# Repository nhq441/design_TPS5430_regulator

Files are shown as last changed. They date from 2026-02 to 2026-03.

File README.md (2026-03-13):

# TPS5430 Dual Buck Converter Module










---

## 📖 Introduction

This project presents the design and implementation of a **DC/DC Buck Converter (Step-Down) Power Supply Module** using **two Texas Instruments TPS5430** ICs. The module accepts a wide input voltage range of **14.4V – 25.2V** and delivers multiple regulated output rails suitable for embedded systems and microcontroller-based applications.

Key features include a **3-mode adjustable main output (VP)**, dual auxiliary LDO rails, a **Power Good LED indicator**, and a **configurable overcurrent protection** threshold set via a shunt resistor.

**Course:** Power Electronics and Applications — Course Code: `BTL_DTCSUD`

---

## 🖼️ PCB Images

### Schematic Overview
> 📷 *[Insert full schematic image here]*

---

### PCB Layout — Top Layer


---

### PCB Layout — Bottom Layer


---

### 3D Render




---

### Assembled Board
> 📷 *[Insert photo of the soldered/assembled board here]*

---

## ⚙️ Technical Specifications

| Parameter | Value | Notes |
| :--- | :--- | :--- |
| **Input Voltage ($V_{IN}$)** | 14.4V – 25.2V | Recommended operating range |
| **Main Output VP** | **5V / 12V / 3.3–12V** | 3 selectable modes |
| **VP Output Current** | Max **3A** | High-efficiency switching mode |
| **Auxiliary Output 1** | **5V** | Via LDO, for logic circuits |
| **Auxiliary Output 2** | **3.3V** | Via LDO, for MCUs (ESP32, STM32, etc.) |
| **Switching Frequency** | 500 kHz | Fixed internal oscillator |
| **Buck IC** | 2× TPS5430 | Texas Instruments |
| **Overcurrent Protection** | Configurable | Set via shunt resistor value |
| **Power Good Indicator** | LED (VP rail) | Signals stable output on VP |

---

## 🛠️ Design Details

### 1. Dual TPS5430 Architecture

The module employs **two independent TPS5430 ICs**:
- **IC1:** Drives the main output rail **VP**, supporting 3 selectable voltage modes.
- **IC2:** *(Describe the role of the second IC here — e.g., secondary rail, redundancy, or higher current capacity)*

### 2. Three-Mode Main Output (VP)

The VP rail supports three operating modes, selected via a switch or jumper:

| Mode | Output Voltage | Configuration |
| :---: | :---: | :--- |
| **Mode 1** | **5V** | Fixed feedback resistor network |
| **Mode 2** | **12V** | Fixed feedback resistor network |
| **Mode 3** | **3.3V – 12V** | Adjustable via potentiometer |

### 3. Feedback Network Calculation

The output voltage is set by a resistor divider ($R_1$, $R_2$) connected to the **VSENSE** pin, based on the internal reference $V_{ref} = 1.221V$:

$$V_{OUT} = V_{ref} \times \left(1 + \frac{R_1}{R_2}\right)$$

**With $R_1 = 10k\Omega$ (fixed):**

- **5V Mode:**

$$R_2 = \frac{R_1 \times V_{ref}}{V_{OUT} - V_{ref}} = \frac{10000 \times 1.221}{5.0 - 1.221} \approx 3.24k\Omega$$

- **12V Mode:**

$$R_2 = \frac{10000 \times 1.221}{12.0 - 1.221} \approx 1.13k\Omega$$

- **Variable Mode:** $R_2$ is replaced with a **5kΩ potentiometer in series with a 1kΩ fixed resistor**, allowing continuous adjustment from **3.3V to 12V**.

### 4. Auxiliary LDO Outputs (5V & 3.3V)

Both LDO regulators are cascaded from the **5V Buck output**, not directly from $V_{IN}$:
- **Reason:** Reduces the voltage drop across each LDO, minimizing power dissipation ($P_D = \Delta V \times I_{load}$).
- **Benefit:** Allows the use of compact packages (e.g., SOT-223) without thermal issues.

### 5. Power Good LED Indicator

A **Power Good LED** is connected to the VP rail. The LED lights up when VP reaches its target voltage, confirming stable regulation before connecting a load.

### 6. Configurable Overcurrent Protection

A **low-side shunt resistor** sets the overcurrent trip threshold. Changing the resistor value adjusts the protection level to match the target application's requirements. The sensing node is labeled **ISENSE** in the schematic.

---

## 📂 Project Structure

```text
BTL_DTCSUD/
├── docs/                       # Documentation & Report files
│   └── ...
├── Kicad/                      # Hardware Design Files
│   └── Buck_TPS5430/
│       ├── *.kicad_sch         # Schematic file
│       ├── *.kicad_pcb         # PCB Layout file
│       └── ...
├── reference/                  # Datasheets & Assignment requirements
│   └── ...
├── .gitignore
├── GIT_GUIDE
└── README.md
```

---

## 🚀 Getting Started

### Prerequisites
- **[KiCad EDA](https://www.kicad.org/)** — Version 9.0 or higher recommended
- **[Git](https://git-scm.com/)** — For version control

### Installation

**Option 1: Clone via Git (Recommended)**
```bash
git clone https://github.com/nhq441/design_TPS5430_regulator.git
```

**Option 2: Download ZIP**
1. Click the green **<> Code** button at the top right of this repository page.
2. Select **Download ZIP**.
3. Extract the `.zip` file to your working directory.

### Opening the Project
1. Launch **KiCad**.
2. Navigate to: `Kicad/Buck_TPS5430/`
3. Open: `Buck_TPS5430.kicad_pro`

---

## 🤝 Contributing

This project follows the **Gitflow Workflow**:

- **`main`**: Stable, verified designs only.
- **`develop`**: Primary integration branch for ongoing work.
- **`feature/*`**: Individual feature branches (e.g., `feature/Schematic`, `feature/PCB-Layout`).
  - Always branch from `develop` and merge back via Pull Request.

---

## 📄 License

This project is developed for **educational purposes** within the scope of the **Power Electronics and Applications** course.

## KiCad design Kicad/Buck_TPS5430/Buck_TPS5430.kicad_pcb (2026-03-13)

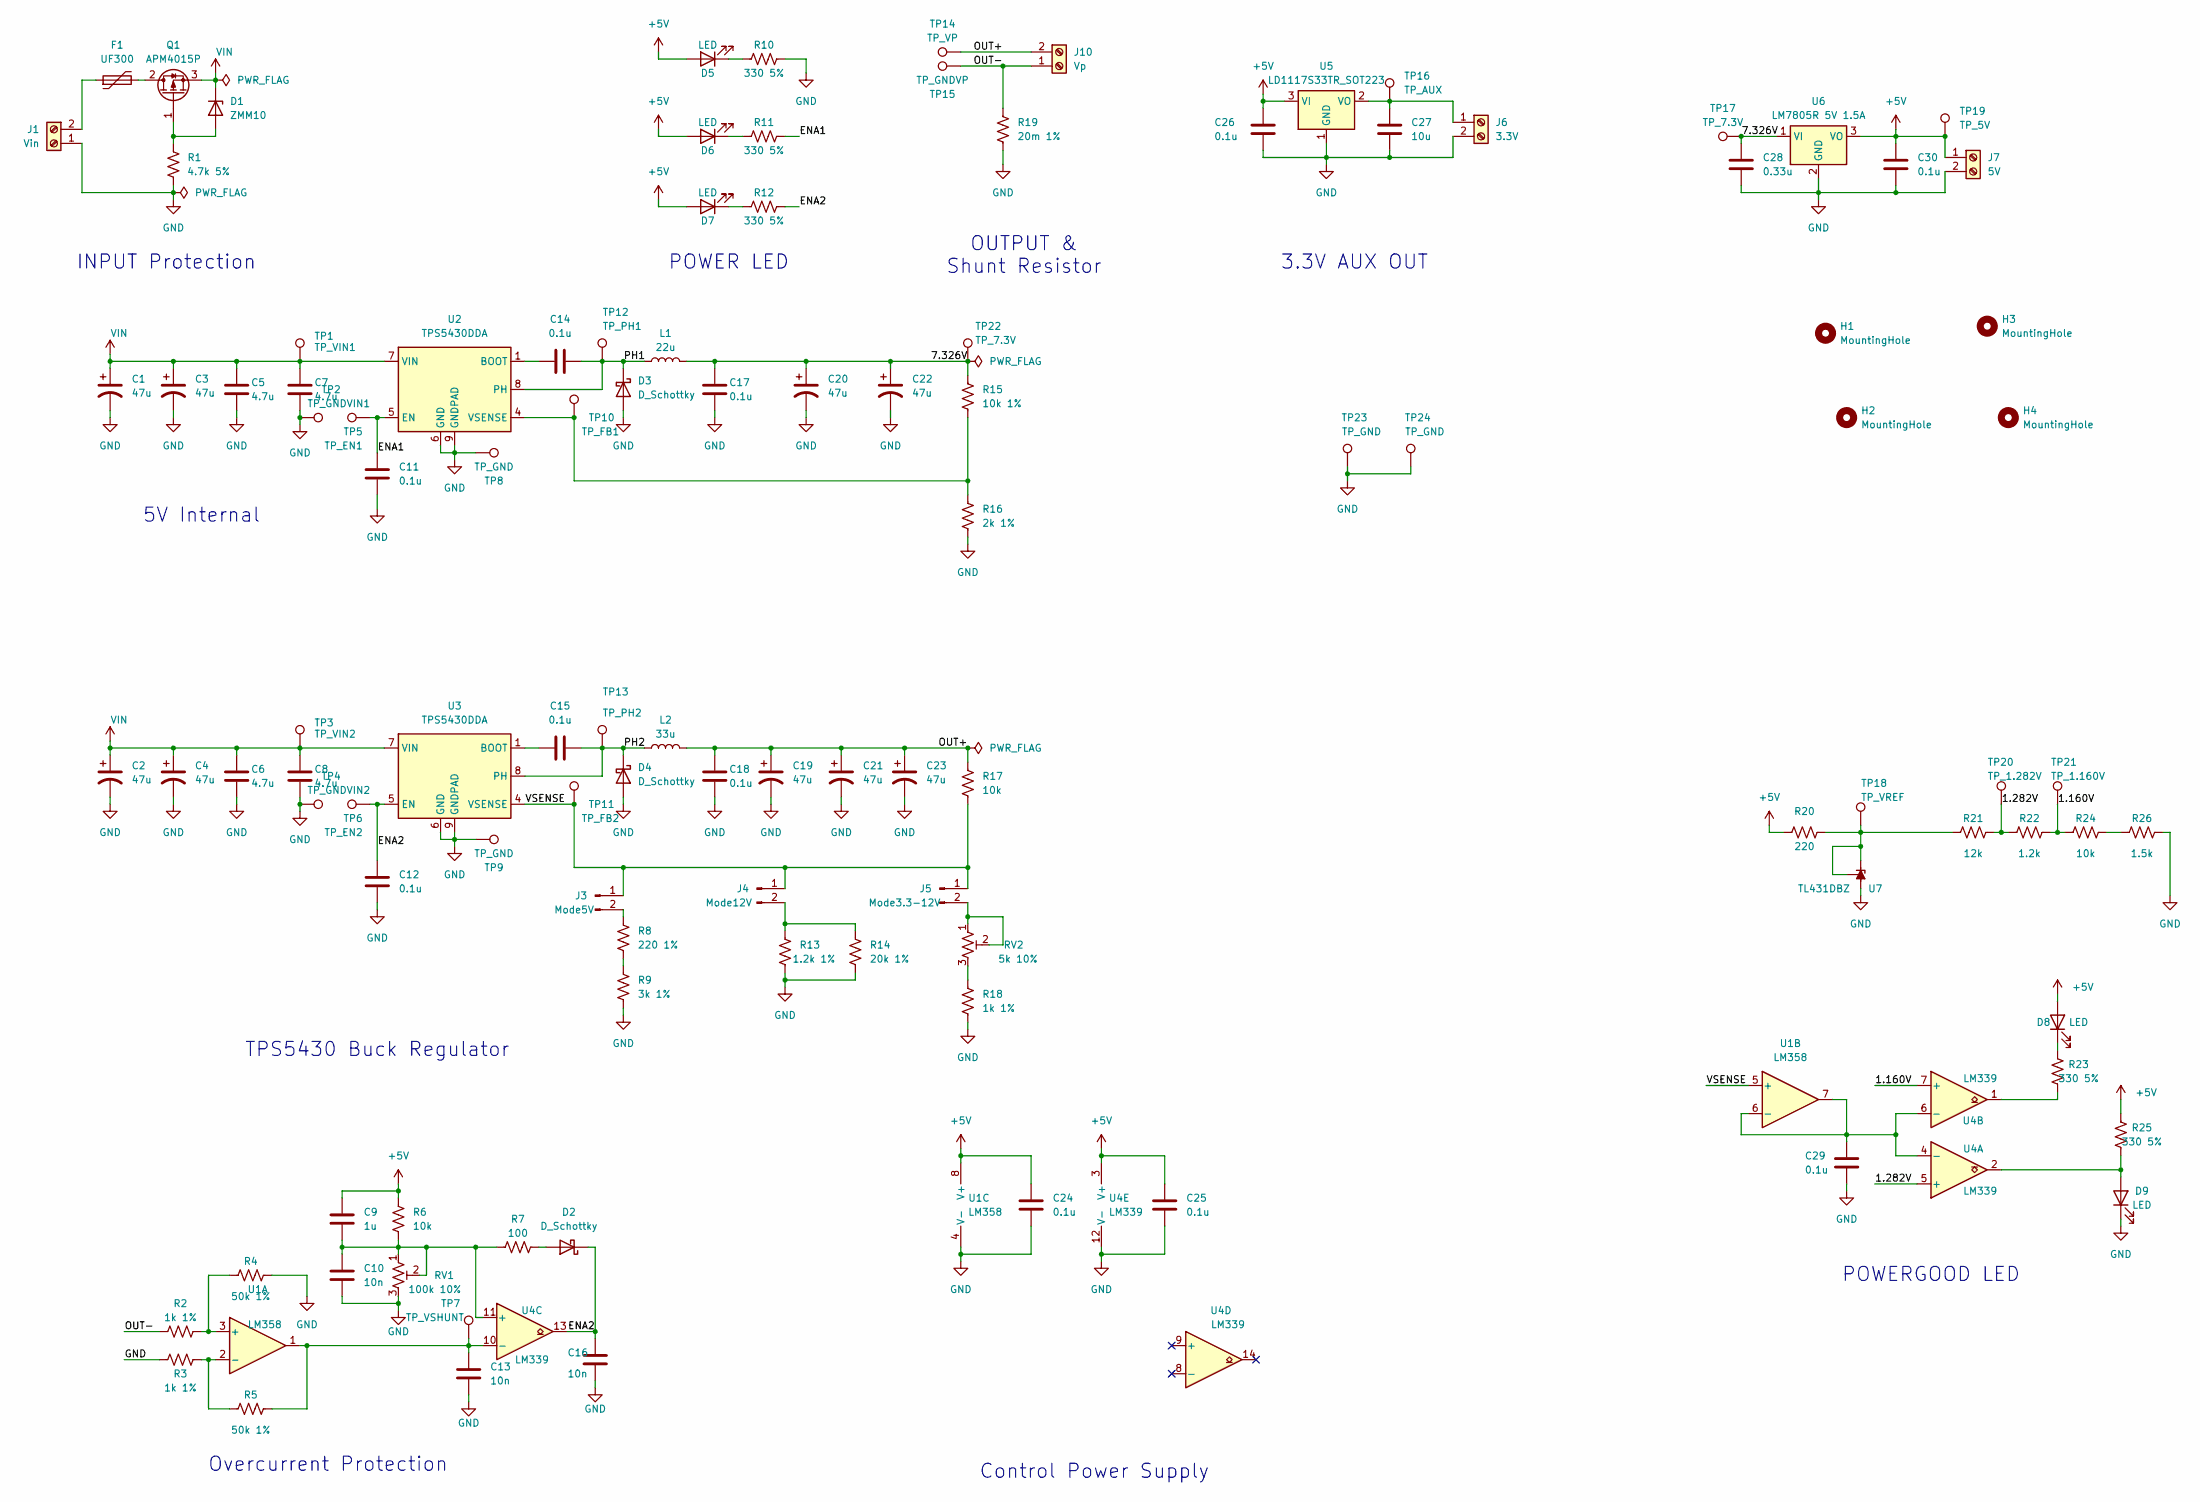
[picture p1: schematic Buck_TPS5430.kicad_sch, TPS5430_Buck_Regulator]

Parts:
C1, C2, C3, C4, C19, C20, C21, C22, C23: 47u; CP_Elec_6.3x7.7
C5, C6, C7, C8: 4.7u; C_0805_2012Metric_Pad1.18x1.45mm_HandSolder
C9: 1u; C_0805_2012Metric_Pad1.18x1.45mm_HandSolder
C10, C13, C16: 10n; C_0805_2012Metric_Pad1.18x1.45mm_HandSolder
C11, C12, C14, C15, C17, C18, C24, C25, C26, C29, C30: 0.1u; C_0805_2012Metric_Pad1.18x1.45mm_HandSolder
C27: 10u; C_0805_2012Metric_Pad1.18x1.45mm_HandSolder
C28: 0.33u; C_0805_2012Metric_Pad1.18x1.45mm_HandSolder
D1: ZMM10; D_MiniMELF
D2, D3, D4: D_Schottky; D_SMC
D5, D6, D7, D8, D9: LED; LED_0805_2012Metric_Pad1.15x1.40mm_HandSolder
F1: UF300; C_Disc_D11.0mm_W5.0mm_P5.00mm
H1, H2, H3, H4: MountingHole; MountingHole_3.2mm_M3
J1: Vin; TerminalBlock_Phoenix_MKDS-1,5-2-5.08_1x02_P5.08mm_Horizont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
J3: Mode5V; PinHeader_1x02_P2.54mm_Vertical
J4: Mode12V; PinHeader_1x02_P2.54mm_Vertical
J5: Mode3.3-12V; PinHeader_1x02_P2.54mm_Vertical
J6: 3.3V; TerminalBlock_Phoenix_MKDS-1,5-2-5.08_1x02_P5.08mm_Horizont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
J7: 5V; TerminalBlock_Phoenix_MKDS-1,5-2-5.08_1x02_P5.08mm_Horizont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
J10: Vp; TerminalBlock_Phoenix_MKDS-1,5-2-5.08_1x02_P5.08mm_Horizont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
L1: 22u; L_Coilcraft_MSS1038-XXX
L2: 33u; L_Coilcraft_MSS1278-XXX
Q1: APM4015P; TO-252-2
R1: 4.7k 5%; R_0805_2012Metric_Pad1.20x1.40mm_HandSolder
R2, R3, R18: 1k 1%; R_0805_2012Metric_Pad1.20x1.40mm_HandSolder
R4, R5: 50k 1%; R_0805_2012Metric_Pad1.20x1.40mm_HandSolder
R6, R17, R24: 10k; R_0805_2012Metric_Pad1.20x1.40mm_HandSolder
R7: 100; R_0805_2012Metric_Pad1.20x1.40mm_HandSolder
R8: 220 1%; R_0805_2012Metric_Pad1.20x1.40mm_HandSolder
R9: 3k 1%; R_0805_2012Metric_Pad1.20x1.40mm_HandSolder
R10, R11, R12, R23, R25: 330 5%; R_0805_2012Metric_Pad1.20x1.40mm_HandSolder
R13: 1.2k 1%; R_0805_2012Metric_Pad1.20x1.40mm_HandSolder
R14: 20k 1%; R_0805_2012Metric_Pad1.20x1.40mm_HandSolder
R15: 10k 1%; R_0805_2012Metric_Pad1.20x1.40mm_HandSolder
R16: 2k 1%; R_0805_2012Metric_Pad1.20x1.40mm_HandSolder
R19: 20m 1%; R_2512_6332Metric_Pad1.40x3.35mm_HandSolder
R20: 220; R_0805_2012Metric_Pad1.20x1.40mm_HandSolder
R21: 12k; R_0805_2012Metric_Pad1.20x1.40mm_HandSolder
R22: 1.2k; R_0805_2012Metric_Pad1.20x1.40mm_HandSolder
R26: 1.5k; R_0805_2012Metric_Pad1.20x1.40mm_HandSolder
RV1: 100k 10%; Potentiometer_Bourns_3296W_Vertical
RV2: 5k 10%; Potentiometer_Bourns_3296W_Vertical
TP1: TP_VIN1; TestPoint_Pad_D1.0mm
TP2: TP_GNDVIN1; TestPoint_Pad_D1.0mm
TP3: TP_VIN2; TestPoint_Pad_D1.0mm
TP4: TP_GNDVIN2; TestPoint_Pad_D1.0mm
TP5: TP_EN1; TestPoint_Pad_D1.0mm
TP6: TP_EN2; TestPoint_Pad_D1.0mm
TP7: TP_VSHUNT; TestPoint_Pad_D1.0mm
TP8, TP9, TP23, TP24: TP_GND; TestPoint_Pad_D1.0mm
TP10: TP_FB1; TestPoint_Pad_D1.0mm
TP11: TP_FB2; TestPoint_Pad_D1.0mm
TP12: TP_PH1; TestPoint_Pad_D1.0mm
TP13: TP_PH2; TestPoint_Pad_D1.0mm
TP14: TP_VP; TestPoint_Pad_D1.0mm
TP15: TP_GNDVP; TestPoint_Pad_D1.0mm
TP16: TP_AUX; TestPoint_Pad_D1.0mm
TP17, TP22: TP_7.3V; TestPoint_Pad_D1.0mm
TP18: TP_VREF; TestPoint_Pad_D1.0mm
TP19: TP_5V; TestPoint_Pad_D1.0mm
TP20: TP_1.282V; TestPoint_Pad_D1.0mm
TP21: TP_1.160V; TestPoint_Pad_D1.0mm
U1: LM358; SOIC-8_3.9x4.9mm_P1.27mm
U2, U3: TPS5430DDA; TI_SO-PowerPAD-8_ThermalVias
U4: LM339; SOIC-14_3.9x8.7mm_P1.27mm
U5: LD1117S33TR_SOT223; SOT-223-3_TabPin2
U6: LM7805R 5V 1.5A; TO-263-3_TabPin2
U7: TL431DBZ; SOT-23

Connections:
+5V: C9.1, C24.1, C25.1, C26.2, C30.1, D5.2 (A), D6.2 (A), D7.2 (A), D8.2 (A), J7.1, R6.2, R20.1, R25.2, TP19.1, U1.8 (V+), U4.3 (V+), U5.3 (VI), U6.3 (VO)
/1.160V: R22.2, R24.1, TP21.1, U4.7 (+)
/1.282V: R21.2, R22.1, TP20.1, U4.5 (+)
/7.326V: C17.1, C20.1, C22.1, C28.1, L1.2, R15.1, TP17.1, TP22.1, U6.1 (VI)
/ENA1: C11.1, R11.1, TP5.1, U2.5 (EN)
/ENA2: C12.1, C16.1, D2.1 (K), R12.1, TP6.1, U3.5 (EN), U4.13
/OUT+: C18.1, C19.1, C21.1, C23.1, J10.2 (Pin_1), L2.2, R17.1, TP14.1
/OUT-: J10.1 (Pin_2), R2.1, R19.1, TP15.1
/PH1: C14.2, D3.1 (K), L1.1, TP12.1, U2.8 (PH)
/PH2: C15.2, D4.1 (K), L2.1, TP13.1, U3.8 (PH)
/VSENSE: J3.1, J4.1, J5.1, R17.2, TP11.1, U1.5 (+), U3.4 (VSENSE)
GND: C1.2, C2.2, C3.2, C4.2, C5.2, C6.2, C7.2, C8.2, C10.2, C11.2, C12.2, C13.2, C16.2, C17.2, C18.2, C19.2, C20.2, C21.2, C22.2, C23.2, C24.2, C25.2, C26.1, C27.1, C28.2, C29.1, C30.2, D3.2 (A), D4.2 (A), D9.1 (K), J1.1 (Pin_2), J6.2, J7.2, R1.2, R3.1, R4.2, R9.2, R10.1, R13.2, R14.2, R16.1, R18.1, R19.2, R26.2, RV1.3, TP2.1, TP4.1, TP8.1, TP9.1, TP23.1, TP24.1, U1.4 (V-), U2.6 (GND), U2.9 (GNDPAD), U3.6 (GND), U3.9 (GNDPAD), U4.12 (V-), U5.1 (GND), U6.2 (GND), U7.3 (A)
unnamed: D1.2 (A), Q1.1 (G), R1.1
unnamed: D2.2 (A), R7.1
unnamed: D5.1 (K), R10.2
unnamed: D6.1 (K), R11.2
unnamed: D7.1 (K), R12.2
unnamed: D8.1 (K), R23.2
unnamed: D9.2 (A), R25.1, U4.2
unnamed: F1.1, J1.2 (Pin_1)
unnamed: J3.2, R8.1
unnamed: J4.2, R13.1, R14.1
unnamed: J5.2, RV2.1, RV2.2
unnamed: C27.2, J6.1, TP16.1, U5.2 (VO)
unnamed: F1.2, Q1.2 (D)
unnamed: R8.2, R9.1
unnamed: R18.2, RV2.3
unnamed: R23.1, U4.1
unnamed: R24.2, R26.1
unnamed: R2.2, R4.1, U1.3 (+)
unnamed: R3.2, R5.1, U1.2 (-)
unnamed: C29.2, U1.6 (-), U1.7, U4.4 (-), U4.6 (-)
unnamed: C14.1, U2.1 (BOOT)
unnamed: R15.2, R16.2, TP10.1, U2.4 (VSENSE)
unnamed: C15.1, U3.1 (BOOT)
unnamed: C9.2, C10.1, R6.1, R7.2, RV1.1, RV1.2, U4.11 (+)
unnamed: C13.1, R5.2, TP7.1, U1.1, U4.10 (-)
unnamed: R20.2, R21.1, TP18.1, U7.1 (K), U7.2 (REF)
VIN: C1.1, C2.1, C3.1, C4.1, C5.1, C6.1, C7.1, C8.1, D1.1 (K), Q1.3 (S), TP1.1, TP3.1, U2.7 (VIN), U3.7 (VIN)

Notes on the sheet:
TPS5430 Buck Regulator
OUTPUT & Shunt Resistor
POWER LED
3.3V AUX OUT
Overcurrent Protection
POWERGOOD LED
Control Power Supply
5V Internal
INPUT Protection

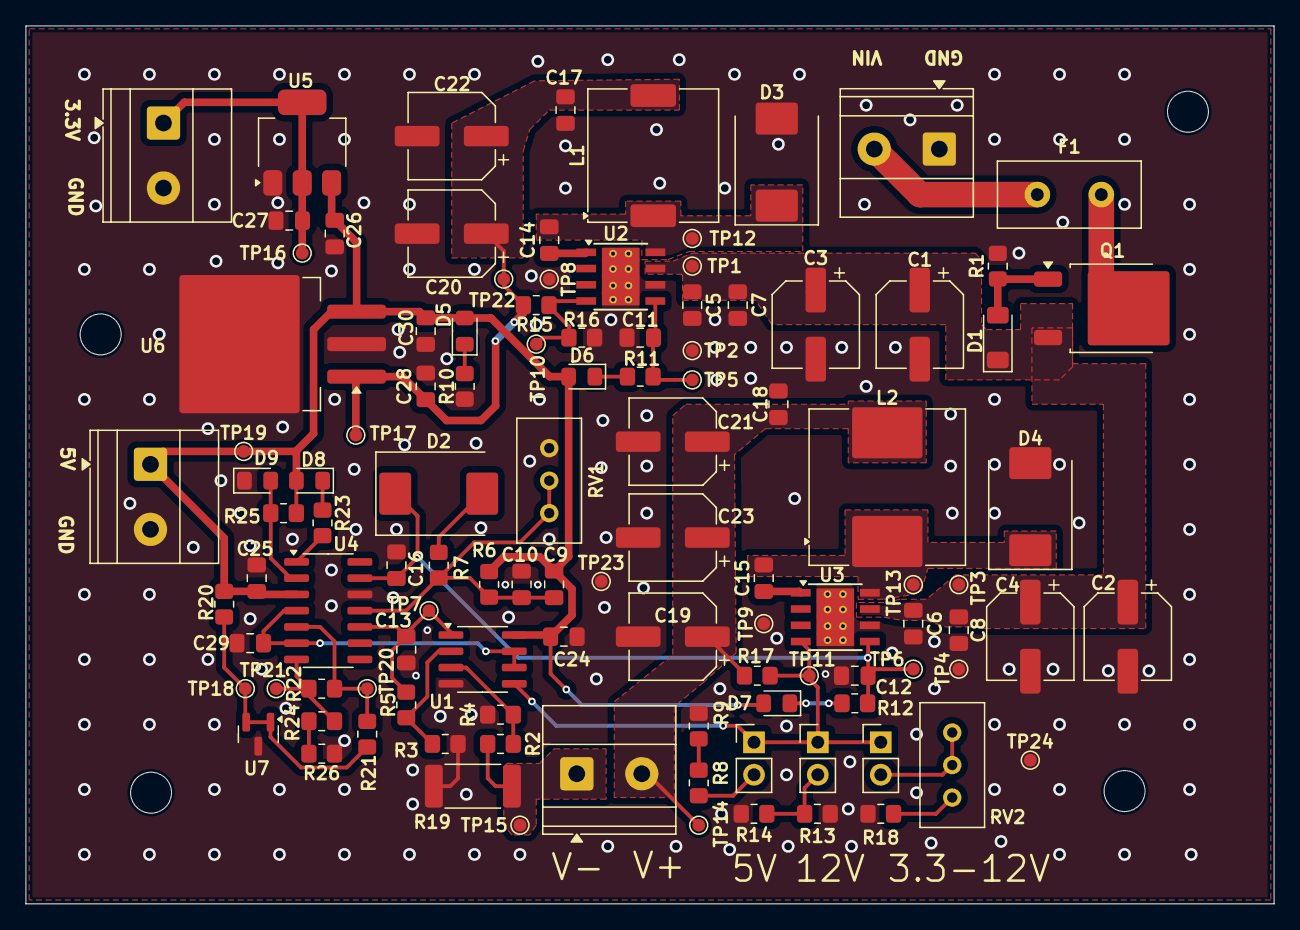
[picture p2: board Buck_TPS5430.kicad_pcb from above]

Board: 2 copper layers, 97.5 x 68.6 mm, 113 parts (0 on the bottom side), 39 nets.

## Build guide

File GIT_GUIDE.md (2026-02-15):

# 📚 Hướng Dẫn Sử Dụng Git cho Dự Án TPS5430




## 📖 Mục Lục
1. [Git là gì?](#git-là-gì)
2. [Cài đặt Git](#cài-đặt-git)
3. [Cấu hình ban đầu](#cấu-hình-ban-đầu)
4. [Các khái niệm cơ bản](#các-khái-niệm-cơ-bản)
5. [Quy trình làm việc (Gitflow)](#quy-trình-làm-việc-gitflow)
6. [Các lệnh Git thường dùng](#các-lệnh-git-thường-dùng)
7. [Hướng dẫn chi tiết từng bước](#hướng-dẫn-chi-tiết-từng-bước)
8. [Xử lý Conflict](#xử-lý-conflict)
9. [Lưu ý quan trọng](#lưu-ý-quan-trọng)
10. [Câu hỏi thường gặp](#câu-hỏi-thường-gặp)

---

## 🤔 Git là gì?

**Git** là một hệ thống quản lý phiên bản phân tán (Version Control System) giúp:
- 📝 Lưu trữ lịch sử thay đổi của dự án
- 👥 Nhiều người cùng làm việc trên một dự án
- 🔄 Quay lại phiên bản cũ khi cần
- 🌿 Phát triển nhiều tính năng song song
- 🔍 Theo dõi ai đã thay đổi gì và khi nào

**Ví dụ thực tế:** Giống như Google Docs có lịch sử chỉnh sửa, nhưng mạnh mẽ hơn nhiều!

---

## 💻 Cài đặt Git

### Windows
1. Tải Git từ: https://git-scm.com/download/win
2. Chạy file cài đặt (`.exe`)
3. Sử dụng các tùy chọn mặc định (nhấn Next liên tục)
4. Khuyến nghị: Chọn "Git Bash" làm terminal

### macOS
```bash
# Sử dụng Homebrew (khuyến nghị)
brew install git

# Hoặc tải từ website
# https://git-scm.com/download/mac
```

### Linux (Ubuntu/Debian)
```bash
sudo apt update
sudo apt install git
```

### Kiểm tra cài đặt
```bash
git --version
# Kết quả mong đợi: git version 2.x.x
```

---

## ⚙️ Cấu hình ban đầu

Sau khi cài đặt Git, bạn cần cấu hình tên và email (chỉ làm 1 lần):

```bash
# Thiết lập tên của bạn
git config --global user.name "Nguyen Van A"

# Thiết lập email của bạn
git config --global user.email "nguyenvana@example.com"

# Kiểm tra cấu hình
git config --list
```

> **💡 Lưu ý:** Tên và email này sẽ xuất hiện trong lịch sử commit. Nên dùng tên thật để mọi người biết ai đã thay đổi code.

---

## 📚 Các khái niệm cơ bản

### 1. Repository (Repo)
**Là gì?** Kho lưu trữ dự án, chứa tất cả file và lịch sử thay đổi.
- **Remote Repository:** Kho trên GitHub/GitLab (kho trung tâm)
- **Local Repository:** Kho trên máy tính của bạn

### 2. Commit
**Là gì?** Một "bản chụp" (snapshot) của dự án tại một thời điểm.
- Mỗi commit có một thông điệp (message) mô tả thay đổi
- Ví dụ: "Thêm sơ đồ mạch cho Buck Converter"

### 3. Branch (Nhánh)
**Là gì?** Một "nhánh" phát triển riêng biệt.
- `main`: Nhánh chính, chứa code ổn định
- `develop`: Nhánh phát triển chung
- `feature/xxx`: Nhánh cho tính năng mới

**Ví dụ:** 
- Bạn A làm sơ đồ mạch trên nhánh `feature/Schematic`
- Bạn B làm PCB trên nhánh `feature/PCB-Layout`
- Sau đó merge (gộp) vào `develop`

### 4. Merge
**Là gì?** Gộp các thay đổi từ nhánh này sang nhánh khác.

### 5. Pull Request (PR)
**Là gì?** Đề xuất merge code của bạn vào nhánh chung.
- Cho phép team review code trước khi merge
- Tránh lỗi và học hỏi lẫn nhau

### 6. Conflict
**Là gì?** Xung đột xảy ra khi 2 người sửa cùng một dòng code.
- Git không biết nên giữ thay đổi của ai
- Bạn cần chọn thủ công

---

## 🌊 Quy trình làm việc (Gitflow)

Dự án của chúng ta sử dụng **Gitflow Workflow**:

```
main (sản phẩm hoàn chỉnh)
  ↑
develop (phát triển chung)
  ↑
feature/Schematic (bạn đang làm)
feature/PCB-Layout (bạn khác đang làm)
```

### Quy tắc làm việc:

1. ⛔ **KHÔNG BAO GIỜ** commit trực tiếp vào `main`
2. ⚠️ **CẨN THẬN** khi commit vào `develop`
3. ✅ **NÊN** tạo nhánh `feature/` cho công việc của mình
4. 🔄 Thường xuyên pull từ `develop` để cập nhật
5. 📝 Viết commit message rõ ràng

---

## 🛠️ Các lệnh Git thường dùng

### Bảng tóm tắt nhanh

| Lệnh | Chức năng |
|---|---|
| `git clone <url>` | Tải dự án về máy |
| `git status` | Xem trạng thái hiện tại |
| `git branch` | Xem danh sách nhánh |
| `git checkout <branch>` | Chuyển sang nhánh khác |
| `git pull` | Cập nhật code mới nhất |
| `git add <file>` | Thêm file vào staging |
| `git commit -m "message"` | Lưu thay đổi |
| `git push` | Đẩy code lên GitHub |
| `git merge <branch>` | Gộp nhánh |

---

## 📋 Hướng dẫn chi tiết từng bước

### 🚀 Bước 1: Clone dự án lần đầu

```bash
# Di chuyển đến thư mục làm việc
cd Desktop

# Clone dự án về máy
git clone https://github.com/nhq441/design_TPS5430_regulator.git

# Vào thư mục dự án
cd design_TPS5430_regulator
```

**Kết quả:** Bạn có một bản sao dự án trên máy.

---

### 🌿 Bước 2: Tạo nhánh feature mới

```bash
# Đảm bảo bạn đang ở nhánh develop
git checkout develop

# Cập nhật develop về mới nhất
git pull origin develop

# Tạo nhánh mới cho công việc của bạn
git checkout -b feature/Ten-Tinh-Nang

# Ví dụ thực tế:
git checkout -b feature/Schematic-Design
# hoặc
git checkout -b feature/PCB-Layout
# hoặc
git checkout -b feature/Add-Documentation
```

**Giải thích:**
- `checkout -b`: Tạo và chuyển sang nhánh mới
- `feature/`: Tiền tố bắt buộc theo Gitflow
- `Ten-Tinh-Nang`: Mô tả ngắn gọn công việc

---

### ✏️ Bước 3: Làm việc và commit

```bash
# 1. Xem file nào đã thay đổi
git status

# 2. Thêm file vào staging (chuẩn bị commit)
# Thêm 1 file cụ thể
git add Kicad/Buck_TPS5430_Project/Buck_TPS5430_Project.kicad_sch

# Hoặc thêm tất cả file thay đổi
git add .

# 3. Commit với message rõ ràng
git commit -m "Thêm sơ đồ mạch Buck Converter TPS5430"

# Ví dụ commit message tốt:
git commit -m "Thêm feedback resistors R1, R2 cho VSENSE"
git commit -m "Sửa lỗi kết nối enable pin"
git commit -m "Cập nhật layout PCB 2 layer"
git commit -m "Thêm tài liệu hướng dẫn tính toán feedback"
```

**❌ Ví dụ commit message XẤU:**
```bash
git commit -m "update"
git commit -m "fix"
git commit -m "abc"
git commit -m "ok"
```

---

### 🔄 Bước 4: Đẩy code lên GitHub

```bash
# Lần đầu push nhánh mới
git push -u origin feature/Ten-Tinh-Nang

# Các lần sau chỉ cần
git push
```

**Giải thích:**
- `-u origin feature/...`: Liên kết nhánh local với remote
- Sau lần đầu, chỉ cần `git push`

---

### 🔀 Bước 5: Tạo Pull Request (trên GitHub)

1. Vào https://github.com/nhq441/design_TPS5430_regulator
2. Bạn sẽ thấy thông báo: "Compare & pull request"
3. Click vào nút đó
4. Điền thông tin:
   - **Title:** Mô tả ngắn gọn (VD: "Thêm sơ đồ mạch Buck Converter")
   - **Description:** Mô tả chi tiết những gì bạn đã làm
   - **Base branch:** Chọn `develop`
   - **Compare branch:** Nhánh feature của bạn
5. Click "Create Pull Request"
6. Đợi team leader review và merge

---

### 🔄 Bước 6: Cập nhật code mới nhất

**Tình huống:** Đồng đội đã merge code mới vào `develop`, bạn cần cập nhật.

```bash
# Chuyển sang nhánh develop
git checkout develop

# Kéo code mới nhất về
git pull origin develop

# Quay lại nhánh feature của bạn
git checkout feature/Ten-Tinh-Nang

# Merge code mới từ develop vào nhánh của bạn
git merge develop
```

**💡 Lưu ý:** Nên làm việc này hàng ngày để tránh conflict lớn!

---

### 🔄 Bước 7: Cập nhật nhánh feature đang làm

**Tình huống:** Bạn đang làm việc, có code mới trên nhánh feature của bạn (do bạn làm trên máy khác hoặc đồng đội làm).

```bash
# Kéo code mới nhất về nhánh hiện tại
git pull
```

---

## ⚔️ Xử lý Conflict

### Conflict xảy ra khi nào?
- 2 người sửa cùng một dòng code
- Một người xóa file, người khác sửa file đó

### Ví dụ conflict:

Giả sử file `README.md` bị conflict:

```
<<<<<<< HEAD
**Output Voltage 1** | **5.0V** | Regulated via TPS5430
=======
**Output Voltage 1** | **5.0V/12V** | Regulated via TPS5430
>>>>>>> develop
```

**Giải thích:**
- `<<<<<<< HEAD`: Phần code của bạn
- `=======`: Dấu phân cách
- `>>>>>>> develop`: Phần code từ develop

### Cách xử lý:

**Cách 1: Dùng editor thủ công**
```bash
# 1. Mở file conflict bằng text editor
# 2. Xóa các dấu conflict (<<<, ===, >>>)
# 3. Chọn code muốn giữ hoặc gộp cả 2
# 4. Lưu file
# 5. Add và commit

git add README.md
git commit -m "Giải quyết conflict trong README.md"
```

**Cách 2: Dùng VS Code (khuyến nghị)**
- VS Code tự động highlight conflict
- Có nút "Accept Current Change", "Accept Incoming Change", "Accept Both"

**Cách 3: Dùng merge tool**
```bash
# KDiff3, Meld, P4Merge...
git mergetool
```

---

## 🎯 Workflow hoàn chỉnh - Ví dụ thực tế

### Ví dụ: Bạn được giao nhiệm vụ thiết kế sơ đồ mạch

```bash
# 1️⃣ Bắt đầu từ develop
git checkout develop
git pull origin develop

# 2️⃣ Tạo nhánh feature
git checkout -b feature/Schematic-Design

# 3️⃣ Mở KiCad, thiết kế sơ đồ
# ... làm việc ...

# 4️⃣ Lưu và commit (làm nhiều lần trong ngày)
git add .
git commit -m "Thêm TPS5430 IC vào schematic"

# Tiếp tục làm việc...
git add .
git commit -m "Thêm input capacitor 100uF"

# Tiếp tục làm việc...
git add .
git commit -m "Thêm feedback resistor network"

# 5️⃣ Push lên GitHub (cuối ngày hoặc khi cần backup)
git push -u origin feature/Schematic-Design

# 6️⃣ Ngày hôm sau, cập nhật develop
git checkout develop
git pull origin develop
git checkout feature/Schematic-Design
git merge develop

# 7️⃣ Tiếp tục làm việc...
git add .
git commit -m "Hoàn thành schematic design"
git push

# 8️⃣ Tạo Pull Request trên GitHub
# Vào GitHub → Compare & Pull Request → Create

# 9️⃣ Sau khi được merge, xóa nhánh feature (tùy chọn)
git checkout develop
git pull origin develop
git branch -d feature/Schematic-Design
```

---

## ⚠️ Lưu ý quan trọng

### ✅ NÊN:
- ✅ Commit thường xuyên (nhiều commit nhỏ > 1 commit lớn)
- ✅ Viết commit message rõ ràng, bằng tiếng Việt hoặc tiếng Anh
- ✅ Pull code mới từ `develop` mỗi ngày
- ✅ Push code lên GitHub thường xuyên (để backup)
- ✅ Tạo nhánh feature riêng cho mỗi tính năng
- ✅ Kiểm tra kỹ trước khi commit (dùng `git status`)

### ❌ KHÔNG NÊN:
- ❌ Commit file không liên quan (file temp, cache, build...)
- ❌ Commit trực tiếp vào `main`
- ❌ Commit code chưa test
- ❌ Dùng `git push -f` (force push) trừ khi biết rõ mình làm gì
- ❌ Commit thông tin nhạy cảm (password, API key)
- ❌ Viết commit message mơ hồ

---

## 🆘 Các tình huống cứu cánh

### 😱 "Tôi commit nhầm file!"

```bash
# Nếu chưa push
git reset HEAD~1  # Hủy commit gần nhất, giữ lại thay đổi
git reset --hard HEAD~1  # Hủy commit và xóa luôn thay đổi
```

### 😱 "Tôi làm sai nhánh!"

```bash
# Bạn đang ở develop nhưng cần ở feature
git stash  # Cất thay đổi tạm thời
git checkout feature/Ten-Nhanh
git stash pop  # Lấy thay đổi ra
```

### 😱 "Tôi muốn hủy tất cả thay đổi chưa commit"

```bash
# Hủy thay đổi của 1 file
git checkout -- ten_file.txt

# Hủy TẤT CẢ thay đổi (⚠️ NGUY HIỂM!)
git reset --hard HEAD
```

### 😱 "Tôi muốn xem ai đã sửa dòng này"

```bash
git blame ten_file.txt
```

### 😱 "Tôi push nhầm, muốn quay lại"

```bash
# ⚠️ CHỈ LÀM NẾU CHƯA AI PULL CODE CỦA BẠN!
git reset --hard HEAD~1
git push -f origin feature/Ten-Nhanh
```

---

## ❓ Câu hỏi thường gặp

### Q: Git khác GitHub như thế nào?
**A:** 
- **Git:** Phần mềm quản lý version (cài trên máy)
- **GitHub:** Website lưu trữ code online (như Google Drive cho code)

### Q: Khi nào nên commit?
**A:** Sau mỗi thay đổi logic hoàn chỉnh. Ví dụ:
- ✅ "Thêm R1, R2 cho feedback network"
- ✅ "Sửa lỗi connection ENA pin"
- ❌ Không nên: Sau mỗi lần nhấn Ctrl+S

### Q: Tôi có thể xóa file commit cũ không?
**A:** Không nên! Git được thiết kế để lưu lịch sử. Nếu thực sự cần, dùng `git rebase` (nâng cao).

### Q: File nào không nên commit?
**A:** 
- File build: `.o`, `.exe`, `.bin`
- File temp: `~`, `.swp`, `.tmp`
- File IDE: `.vscode/`, `.idea/`
- File lớn: video, zip (dùng Git LFS)
- **Đã có `.gitignore` giúp bạn!**

### Q: Pull Request và Merge khác nhau?
**A:**
- **Pull Request:** Đề xuất merge trên GitHub (có review)
- **Merge:** Lệnh Git gộp nhánh (không có review)

### Q: Tôi nên đặt tên nhánh như thế nào?
**A:** 
- Format: `feature/ten-tinh-nang`
- Ví dụ tốt: `feature/add-ldo-circuit`, `feature/pcb-routing`
- Ví dụ xấu: `test`, `my-branch`, `abc`

---

## 📖 Tài liệu tham khảo

### Học thêm về Git
- **Git Book (Tiếng Việt):** https://git-scm.com/book/vi/v2
- **Git Cheat Sheet:** https://education.github.com/git-cheat-sheet-education.pdf
- **Interactive Git Tutorial:** https://learngitbranching.js.org/

### Video hướng dẫn
- Cơ bản: https://www.youtube.com/watch?v=DVRQoVRzMIY (tiếng Việt)
- Nâng cao: https://www.youtube.com/watch?v=Uszj_k0DGsg (tiếng Anh)

---

## 🎓 Bài tập thực hành

### Bài 1: Clone và khám phá
```bash
git clone https://github.com/nhq441/design_TPS5430_regulator.git
cd design_TPS5430_regulator
git log --oneline  # Xem lịch sử commit
git branch -a      # Xem tất cả nhánh
```

### Bài 2: Tạo nhánh và commit
```bash
git checkout -b feature/Practice
echo "Tôi đang học Git" > test.txt
git add test.txt
git commit -m "Thêm file test"
git push -u origin feature/Practice
```

### Bài 3: Merge và xử lý conflict

**Mục tiêu:** Học cách merge nhánh và xử lý conflict cơ bản

#### Bước 1: Tạo 2 nhánh để thực hành
```bash
# Tạo file test chung
git checkout develop
echo "Line 1: Original content" > conflict_test.txt
git add conflict_test.txt
git commit -m "Add conflict test file"
git push

# Tạo nhánh A và sửa file
git checkout -b feature/test-A
echo "Line 1: Modified by Person A" > conflict_test.txt
git add conflict_test.txt
git commit -m "Person A changes"
git push -u origin feature/test-A

# Quay lại develop và tạo nhánh B
git checkout develop
git checkout -b feature/test-B
echo "Line 1: Modified by Person B" > conflict_test.txt
git add conflict_test.txt
git commit -m "Person B changes"
git push -u origin feature/test-B
```

#### Bước 2: Thử merge (sẽ gặp conflict)
```bash
# Ở nhánh feature/test-B, merge nhánh feature/test-A
git checkout feature/test-B
git merge feature/test-A
# Kết quả: CONFLICT! 🔥
```

#### Bước 3: Xử lý conflict
```bash
# Xem file bị conflict
cat conflict_test.txt
# Sẽ thấy:
# <<<<<<< HEAD
# Line 1: Modified by Person B
# =======
# Line 1: Modified by Person A
# >>>>>>> feature/test-A

# Mở file bằng editor và sửa thành:
# Line 1: Modified by Person A and B

# Sau khi sửa xong:
git add conflict_test.txt
git commit -m "Resolve conflict between A and B"
git push
```

#### Bước 4: Dọn dẹp
```bash
# Xóa các nhánh test
git checkout develop
git branch -d feature/test-A
git branch -d feature/test-B
git push origin --delete feature/test-A
git push origin --delete feature/test-B
```

**💡 Mẹo:** 
- Dùng VS Code để xử lý conflict dễ hơn (có nút Accept Current/Incoming Change)
- Nếu conflict phức tạp, hỏi người gây conflict để quyết định giữ code nào
- **Nếu gặp lỗi hoặc không biết xử lý, liên hệ hỗ trợ ngay!**

---

## 📞 Liên hệ hỗ trợ

Nếu gặp vấn đề:
1. 🔍 Google lỗi (90% đã có người gặp)
2. 💬 Hỏi team trên Zalo/Slack
3. 📧 Email team leader
4. 🌐 Đọc tài liệu Git Book

---

## 🎉 Kết luận

Git nghe có vẻ phức tạp nhưng bạn chỉ cần nhớ:

```
1. git pull      → Lấy code mới
2. (làm việc)
3. git add .     → Chuẩn bị commit
4. git commit    → Lưu thay đổi
5. git push      → Đẩy lên GitHub
```

**Thực hành nhiều là thành thạo!** 💪

---

*Tài liệu được tạo cho dự án TPS5430 Buck Converter*  
*Cập nhật lần cuối: Tháng 2, 2026*🚀

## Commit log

2026-02-05 feat: draw basic schematic tps543s
    [Buck_TPS5430_Project.kicad_pcb, Buck_TPS5430_Project.kicad_sch]
2026-02-06 Revise README for TPS5430 Buck Converter Module
    Updated project details and specifications in README.
2026-02-11 WIP: add capacitor and powergood led
    [Buck_TPS5430_Project.kicad_sch]
2026-02-12 WIP: compelete powergood led and add short current protection
    [Buck_TPS5430_Project.kicad_sch]
2026-02-14 feat: finish schematic topology (values TBD - to be determined)
    [Buck_TPS5430_Project.kicad_sch]
2026-02-15 Cập nhật tài liệu hướng dẫn Git cho dự án TPS5430
    Cập nhật hướng dẫn sử dụng Git cho dự án TPS5430, bao gồm các khái niệm cơ bản, quy trình làm việc và các lệnh Git thường dùng.
2026-03-07 feat: add 5v buck, edit logic of power led, calculate R, L, C
    [Buck_TPS5430_Project.kicad_sch]
2026-03-12 feat:PCB layout
    [Buck_TPS5430_Project.kicad_pcb, Buck_TPS5430_Project.kicad_sch]
2026-03-13 feat: COMPLETE PCB Layout
    [Buck_TPS5430.kicad_pcb, Buck_TPS5430.kicad_sch, Buck_TPS5430_Project.kicad_pcb]

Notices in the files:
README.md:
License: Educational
